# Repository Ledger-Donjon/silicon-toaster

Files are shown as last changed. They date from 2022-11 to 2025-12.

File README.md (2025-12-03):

# SiliconToaster

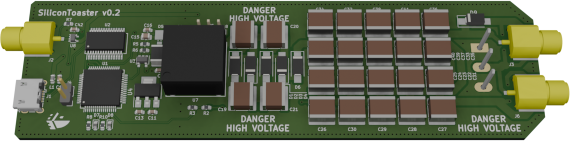
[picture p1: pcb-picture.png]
SiliconToaster


SiliconToaster is an open-source hardware electromagnetic fault injection device, designed for hardware security research. It has the following features:

- Software programmable voltage, from 0 V to 1000 V.
- Stored energy: 1 J at 1000 V.
- Capable of multiple fault injection.
- Dual socket coil mounting, for polarity selection.
- USB-only powered.

**Warning: this device is experimental and for research purpose only. High-voltage is exposed on the PCB, which can present electrical hazard. Use with caution and at your own risk. Beware that the coil body is connected to the high potential, NOT at the ground. Also, the exposed capacitor bank stores an important amount of energy.**

## Building the firmware

To build the firmware, rust shall be installed on your system (see [instructions](https://www.rust-lang.org/tools/install) for installation).

The rust toolchain for Armv6-M Thumb must be installed:

```
rustup target add thumbv6m-none-eabi
```

The firmware can then be compiled using cargo:

```
cd firmware
cargo objcopy --release --bin silicontoaster -- -O binary silicontoaster.bin
```

To flash the device, stm32flash utility is required. The MCU bootloader can be enabled by shorting the header close to the USB connector using a jumper, before connecting the PCB on USB. Then the following command will flash the MCU (replace `/dev/ttyUSB0` with the serial device in your situation):

```
stm32flash -w silicontoaster.bin -v -g 0 /dev/ttyUSB0
```

Alternatively, a makefile can run those steps:

```
cd firmware
make all
make flash
```

To enable device recognition, the FTDI USB-serial converter must be flashed using ftdi_eeprom tool. Warning: be sure no other FTDI device is connected before running this command!

```
cd ftdi
bash flash.sh
```

## Running the software

To use the device, run `python3 silicontoaster/tool.py`. This will run a graphical interface that allows setting the operating voltage and display in real-time the voltage in the capacitors bank.

When running for the first time, configure the charge pump PID settings to `Kp`, `Ki` and `Kd` to 1. Be sure to have the jumper J5 installed (position closest to the USB).

The provided calibration values should work fine by default, it is not necessary to calibrate the device by yourself unless you want more accurate measurements.

## Publication

This work was published in our [Paper](https://eprint.iacr.org/2020/1115.pdf) and presented during [Hardwear.io 2020 conference](https://hardwear.io/archives/netherlands-2020/).

## Licensing

SiliconToaster is released under GNU Lesser General Public License version 3 (LGPLv3). See LICENSE and LICENSE.LESSER for license detail.

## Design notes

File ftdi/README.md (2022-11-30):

# FTDI EEPROM programming

Disconnect all USB-to-serial devices but the SiliconToaster.

Install the package `ftdi_eeprom` and execute the `flash.sh` script as root to
program the EEPROM memory of the SiliconToaster FT232H device. This will
configure the vendor and description strings to respectively "Ledger" and
"SiliconToaster".

Configuring the EEPROM is optional, but when programmed, the software is able
to recognize automatically which serial port corresponds to the SiliconToaster.

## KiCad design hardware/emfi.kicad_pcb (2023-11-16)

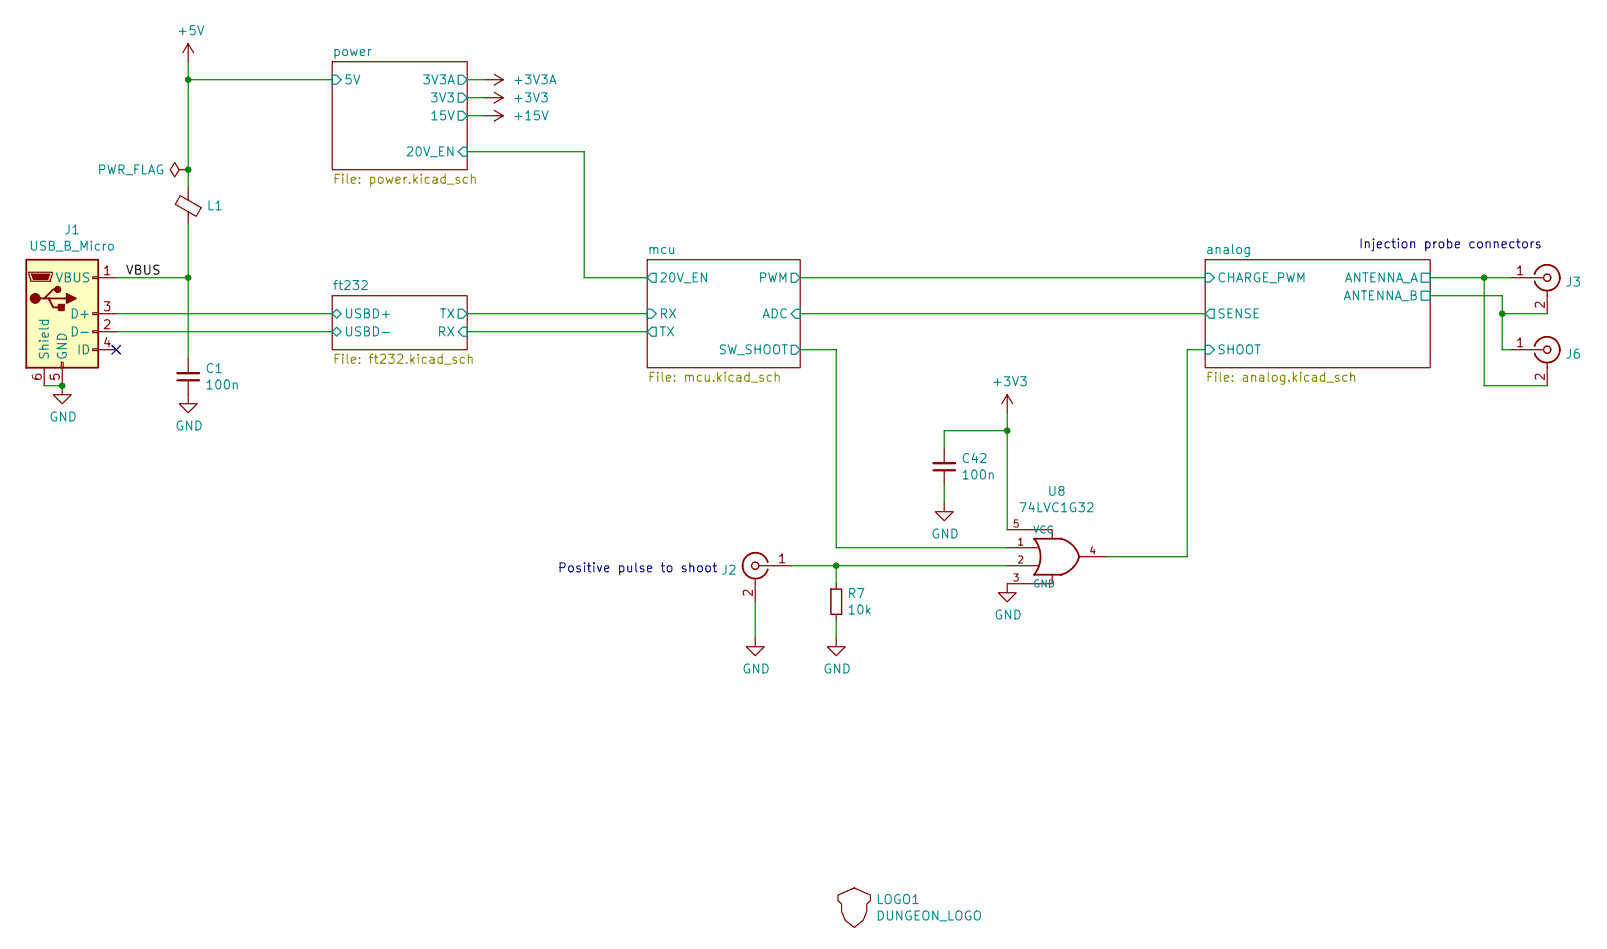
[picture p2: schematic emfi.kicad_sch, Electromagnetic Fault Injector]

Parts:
C1, C42: 100n; C_0603_1608Metric; Voltage 25
J1: USB_B_Micro; USB_Micro-B_Wuerth_629105150521
J2, J3, J6: Conn_Coaxial; SAMTEC_SMA_J_P_H_ST_EM3
L1: Ferrite_Bead_Small; L_0603_1608Metric
LOGO1: DUNGEON_LOGO; donjon-2000
R7: 10k; R_0603_1608Metric
U8: 74LVC1G32; SOT-353_SC-70-5

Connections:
+3V3: C42.2, U8.5 (VCC); also elsewhere on the board
+5V: L1.2; also elsewhere on the board
/VBUS: C1.2, J1.1 (VBUS), L1.1
/analog/ANTENNA_A: J3.1 (In), J6.2 (Ext); also elsewhere on the board
/analog/ANTENNA_B: J3.2 (Ext), J6.1 (In); also elsewhere on the board
/analog/SHOOT: U8.4; also elsewhere on the board
/ft232/USBD+: J1.3 (D+); also elsewhere on the board
/ft232/USBD-: J1.2 (D-); also elsewhere on the board
/mcu/SW_SHOOT: U8.1; also elsewhere on the board
GND: C1.1, C42.1, J1.5 (GND), J1.6 (Shield), J2.2 (Ext), R7.2, U8.3 (GND); also elsewhere on the board
unnamed: J2.1 (In), R7.1, U8.2

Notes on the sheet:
Positive pulse to shoot
Injection probe connectors

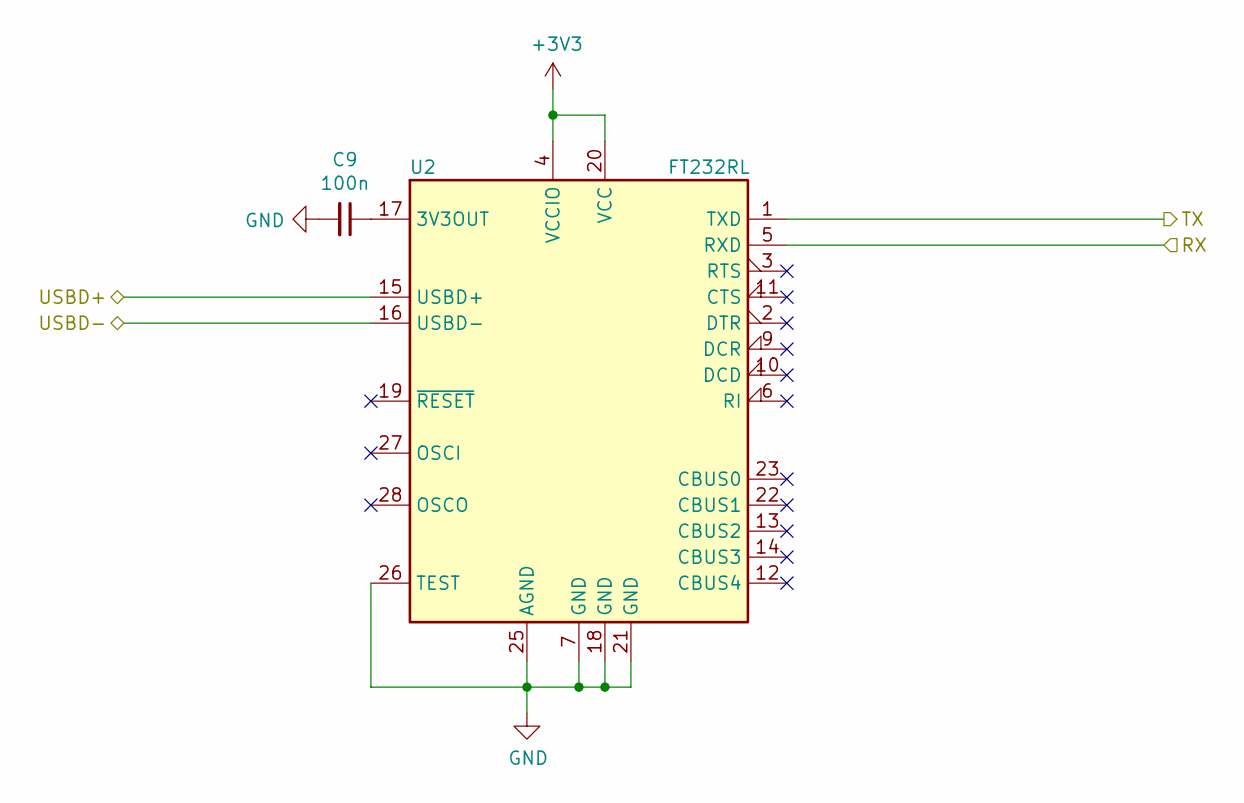
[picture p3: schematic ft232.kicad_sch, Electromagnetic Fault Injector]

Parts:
C9: 100n; C_0603_1608Metric; Voltage 25
U2: FT232RL; SSOP-28_5.3x10.2mm_P0.65mm

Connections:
+3V3: U2.4 (VCCIO), U2.20 (VCC); also elsewhere on the board
/ft232/RX: U2.5 (RXD); also elsewhere on the board
/ft232/USBD+: U2.15 (USBD+); also elsewhere on the board
/ft232/USBD-: U2.16 (USBD-); also elsewhere on the board
/mcu/RX: U2.1 (TXD); also elsewhere on the board
GND: C9.2, U2.7 (GND), U2.18 (GND), U2.21 (GND), U2.25 (AGND), U2.26 (TEST); also elsewhere on the board
unnamed: C9.1, U2.17 (3V3OUT)

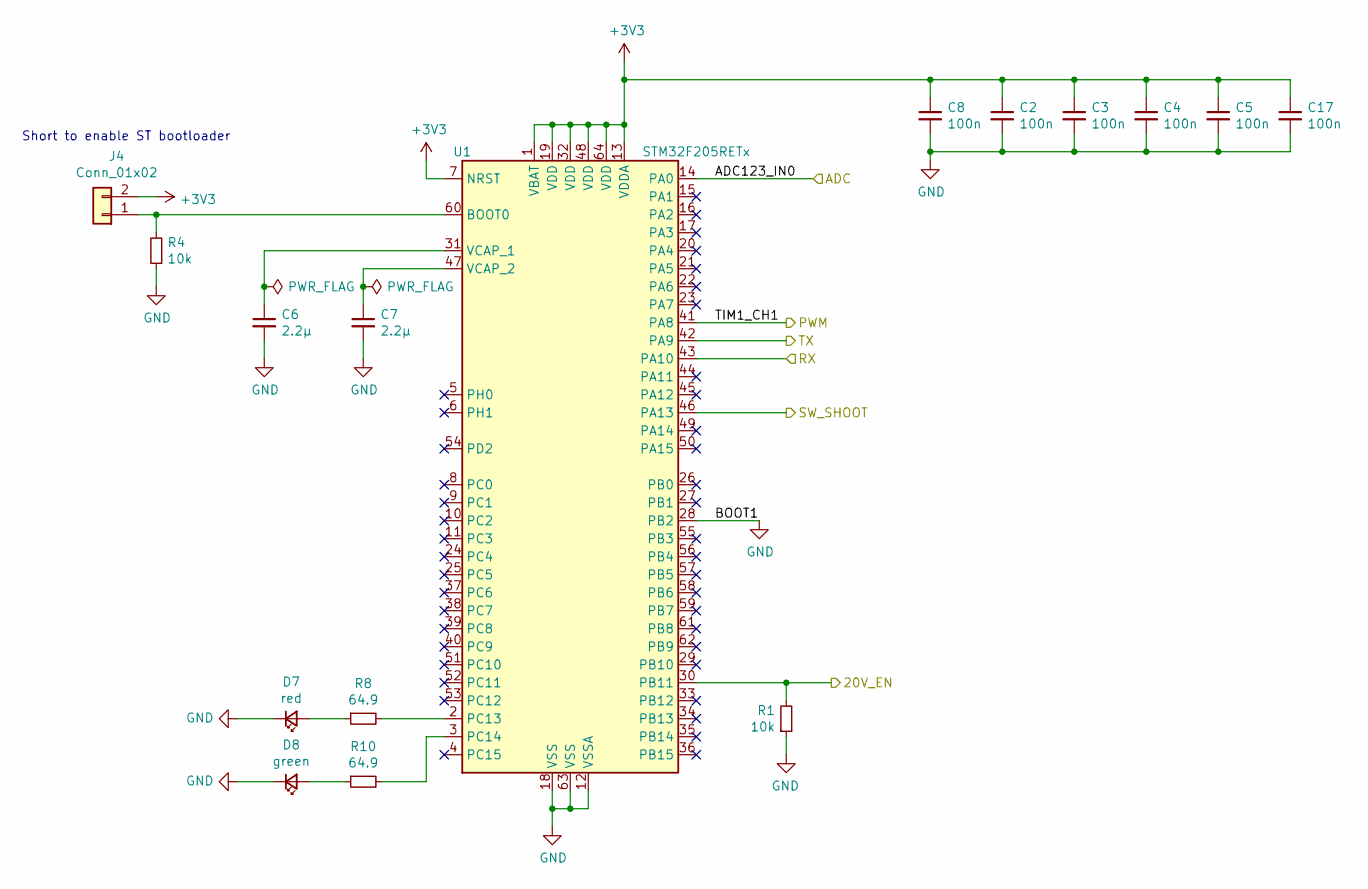
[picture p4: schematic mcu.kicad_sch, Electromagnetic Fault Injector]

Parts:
C2, C3, C4, C5, C8, C17: 100n; C_0603_1608Metric; Voltage 25
C6, C7: 2.2µ; C_0603_1608Metric; Voltage 25
D7: red; D_0603_1608Metric
D8: green; D_0603_1608Metric
J4: Conn_01x02; PinHeader_1x02_P2.54mm_Vertical
R1, R4: 10k; R_0603_1608Metric
R8, R10: 64.9; R_0603_1608Metric
U1: STM32F205RETx; LQFP-64_10x10mm_P0.5mm

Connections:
+3V3: C2.1, C3.1, C4.1, C5.1, C8.1, C17.1, J4.2, U1.1 (VBAT), U1.7 (NRST), U1.13 (VDDA), U1.19 (VDD), U1.32 (VDD), U1.48 (VDD), U1.64 (VDD); also elsewhere on the board
/analog/CHARGE_PWM: U1.41 (PA8); also elsewhere on the board
/ft232/RX: U1.42 (PA9); also elsewhere on the board
/mcu/20V_EN: R1.2, U1.30 (PB11); also elsewhere on the board
/mcu/ADC: U1.14 (PA0); also elsewhere on the board
/mcu/RX: U1.43 (PA10); also elsewhere on the board
/mcu/SW_SHOOT: U1.46 (PA13); also elsewhere on the board
GND: C2.2, C3.2, C4.2, C5.2, C6.2, C7.2, C8.2, C17.2, D7.1 (K), D8.1 (K), R1.1, R4.1, U1.12 (VSSA), U1.18 (VSS), U1.28 (PB2), U1.63 (VSS); also elsewhere on the board
unnamed: C6.1, U1.31 (VCAP_1)
unnamed: C7.1, U1.47 (VCAP_2)
unnamed: D7.2 (A), R8.1
unnamed: D8.2 (A), R10.1
unnamed: J4.1, R4.2, U1.60 (BOOT0)
unnamed: R8.2, U1.2 (PC13)
unnamed: R10.2, U1.3 (PC14)

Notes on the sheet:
Short to enable ST bootloader

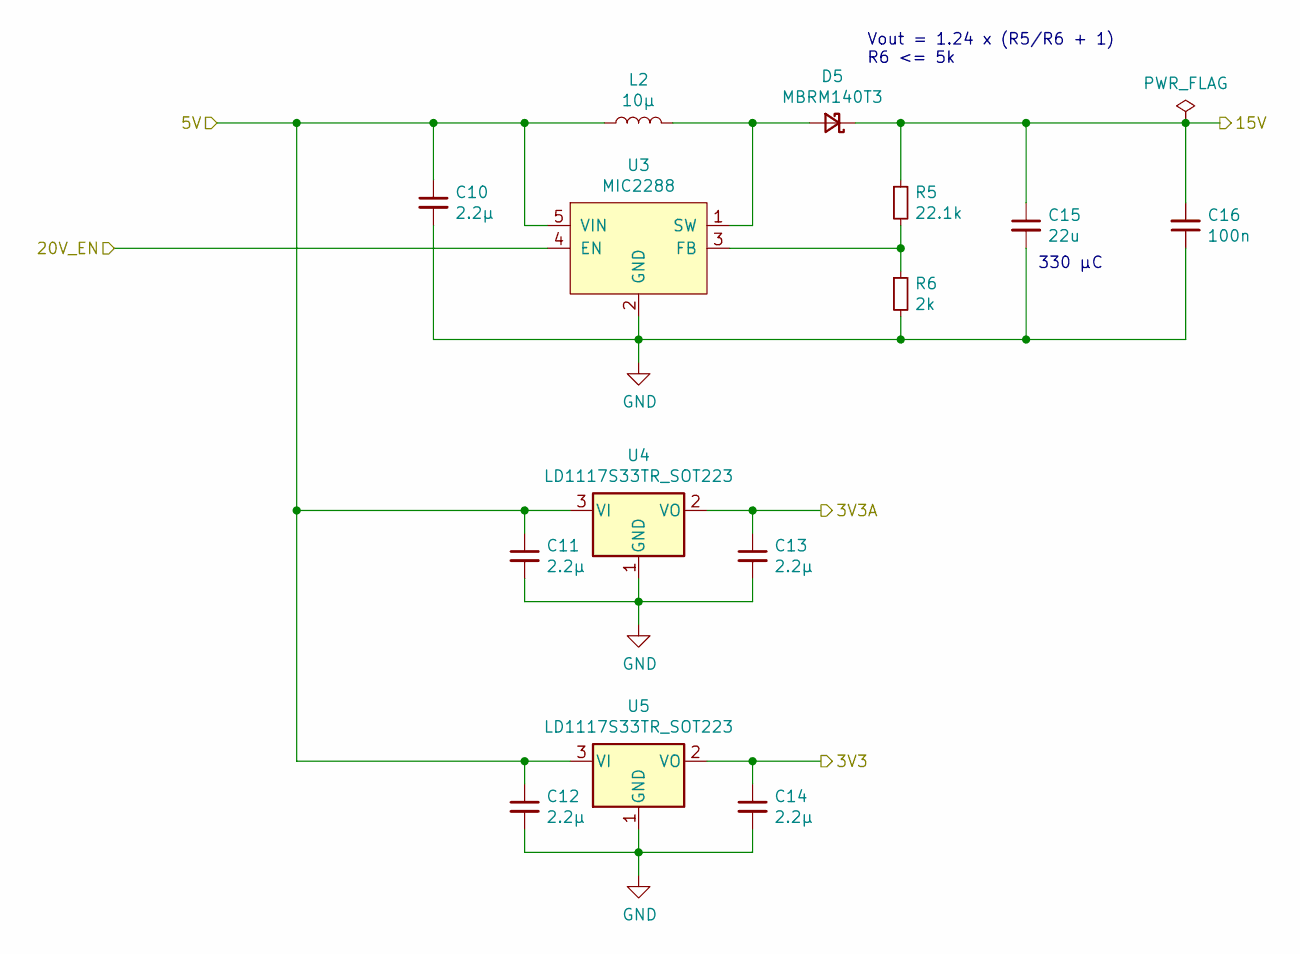
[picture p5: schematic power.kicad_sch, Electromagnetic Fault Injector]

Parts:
C10, C11, C12, C13, C14: 2.2µ; C_0603_1608Metric; Voltage 25
C15: 22u; C_0805_2012Metric; Voltage 25
C16: 100n; C_0603_1608Metric; Voltage 25
D5: MBRM140T3; D_Powermite_AK
L2: 10µ; L_1812_4532Metric
R5: 22.1k; R_0603_1608Metric
R6: 2k; R_0603_1608Metric
U3: MIC2288; SOT-23-5
U4, U5: LD1117S33TR_SOT223; SOT-223-3_TabPin2

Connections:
+3V3: C14.1, U5.2 (VO); also elsewhere on the board
+3V3A: C13.1, U4.2 (VO); also elsewhere on the board
+5V: C10.1, C11.1, C12.1, L2.1, U3.5 (VIN), U4.3 (VI), U5.3 (VI); also elsewhere on the board
+15V: C15.1, C16.2, D5.1 (K), R5.1; also elsewhere on the board
/mcu/20V_EN: U3.4 (EN); also elsewhere on the board
GND: C10.2, C11.2, C12.2, C13.2, C14.2, C15.2, C16.1, R6.2, U3.2 (GND), U4.1 (GND), U5.1 (GND); also elsewhere on the board
unnamed: D5.2 (A), L2.2, U3.1 (SW)
unnamed: R5.2, R6.1, U3.3 (FB)

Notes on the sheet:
330 µC
Vout = 1.24 x (R5/R6 + 1) R6 <= 5k

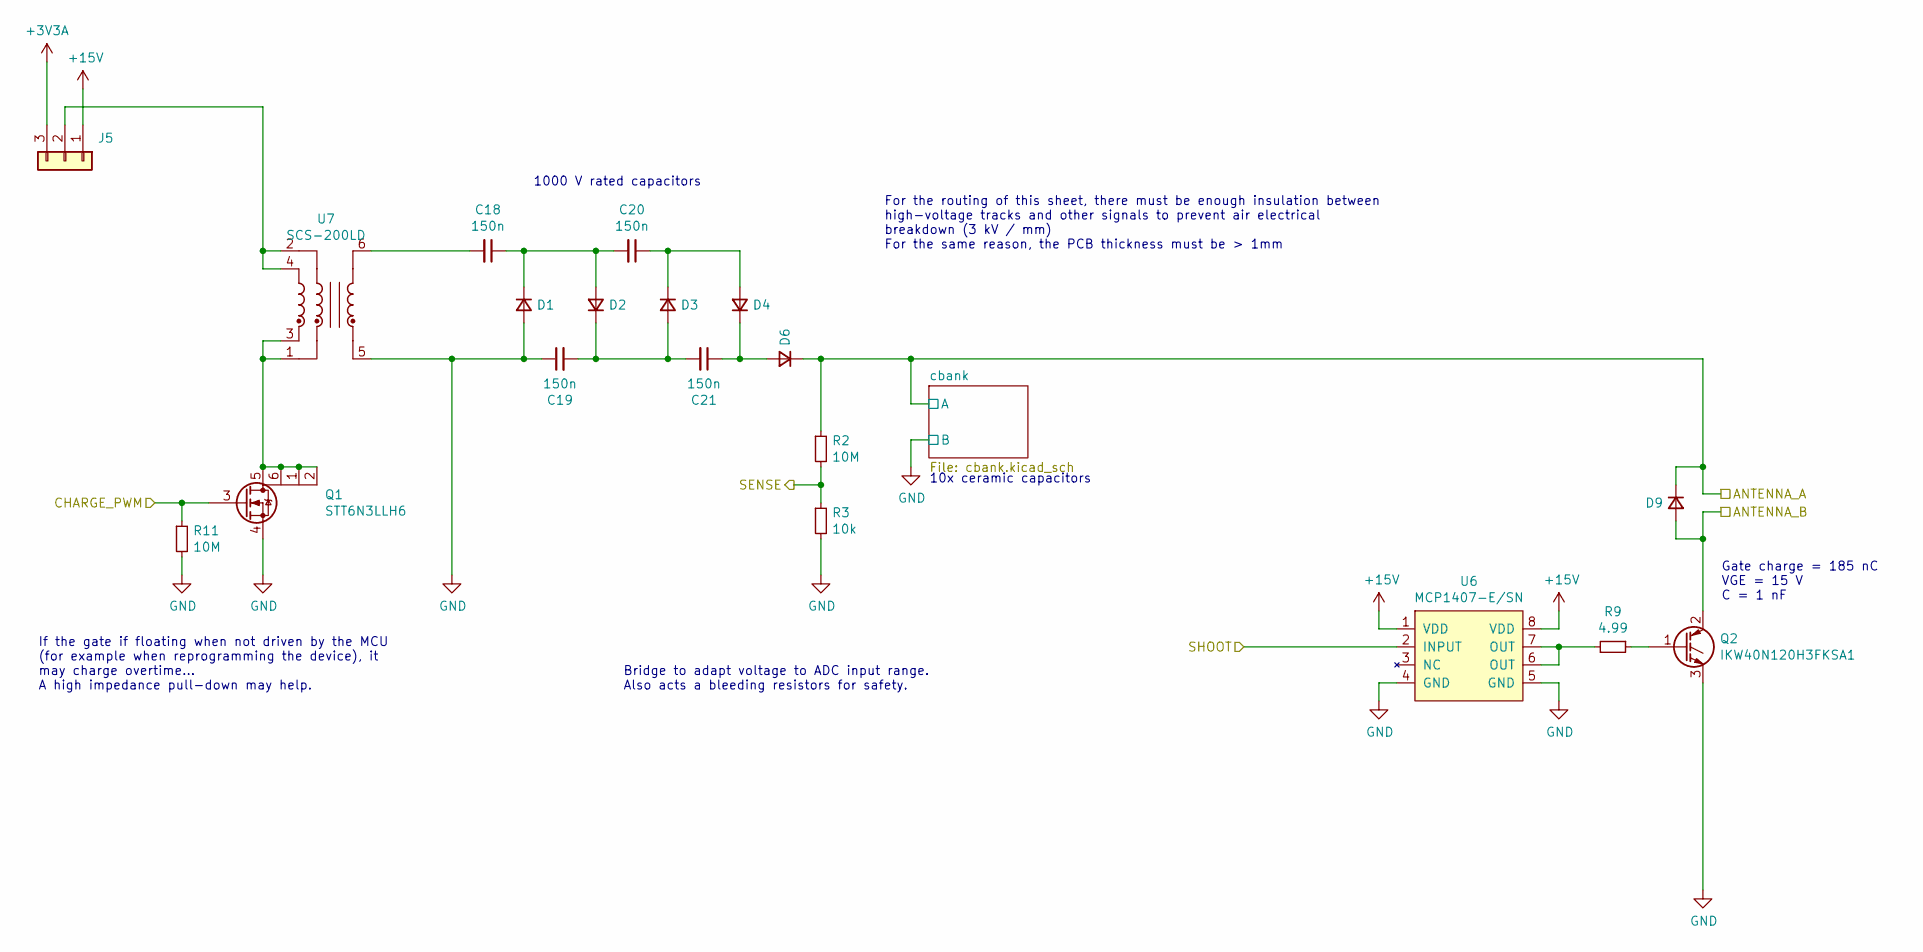
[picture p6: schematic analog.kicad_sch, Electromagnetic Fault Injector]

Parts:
C18, C19, C20, C21: 150n; C_2225_5664Metric_Pad1.80x6.60mm_HandSolder; Voltage 1000
D1, D2, D3, D4, D6, D9: US1K-E3/61T; D_SMA_Handsoldering
J5: Conn_01x03; PinHeader_1x03_P2.54mm_Vertical
Q1: STT6N3LLH6; SOT-23-6
Q2: IKW40N120H3FKSA1; TO-247-3_Horizontal_TabDown_NoTabDrill
R2, R11: 10M; R_0603_1608Metric
R3: 10k; R_0603_1608Metric
R9: 4.99; R_0603_1608Metric
U6: MCP1407-E/SN; SOIC-8_3.9x4.9mm_P1.27mm
U7: SCS-200LD; SCS-200L

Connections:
+3V3A: J5.3; also elsewhere on the board
+15V: J5.1, U6.1 (VDD), U6.8 (VDD); also elsewhere on the board
/analog/ANTENNA_A: D6.1 (K), D9.1 (K), R2.1; also elsewhere on the board
/analog/ANTENNA_B: D9.2 (A), Q2.2 (C); also elsewhere on the board
/analog/CHARGE_PWM: Q1.3, R11.1; also elsewhere on the board
/analog/SHOOT: U6.2 (INPUT); also elsewhere on the board
/mcu/ADC: R2.2, R3.1; also elsewhere on the board
GND: C19.1, D1.2 (A), Q1.4, Q2.3 (E), R3.2, R11.2, U6.4 (GND), U6.5 (GND), U7.5; also elsewhere on the board
unnamed: C18.1, C20.2, D1.1 (K), D2.2 (A)
unnamed: C18.2, U7.6
unnamed: C19.2, C21.2, D2.1 (K), D3.2 (A)
unnamed: C20.1, D3.1 (K), D4.2 (A)
unnamed: C21.1, D4.1 (K), D6.2 (A)
unnamed: J5.2, U7.2, U7.4
unnamed: Q1.1, Q1.2, Q1.5, Q1.6, U7.1, U7.3
unnamed: Q2.1 (G), R9.1
unnamed: R9.2, U6.6 (OUT), U6.7 (OUT)

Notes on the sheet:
10x ceramic capacitors
Gate charge = 185 nC VGE = 15 V C = 1 nF
If the gate if floating when not driven by the MCU (for example when reprogramming the device), it may charge overtime... A high impedance pull-down may help.
For the routing of this sheet, there must be enough insulation between high-voltage tracks and other signals to prevent air electrical breakdown (3 kV / mm) For the same reason, the PCB thickness must be > 1mm
1000 V rated capacitors
Bridge to adapt voltage to ADC input range. Also acts a bleeding resistors for safety.

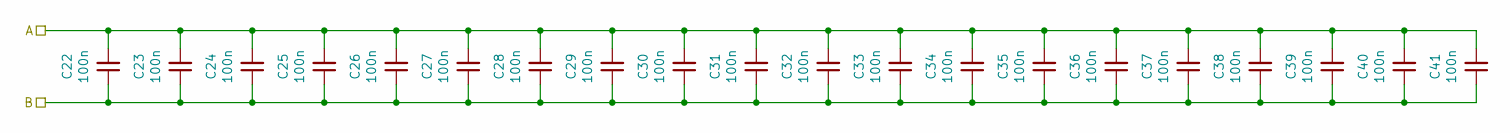
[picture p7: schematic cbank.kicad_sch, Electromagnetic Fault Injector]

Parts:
C22, C23, C24, C25, C26, C27, C28, C29, C30, C31, C32, C33, C34, C35, C36, C37, C38, C39, C40, C41: 100n; C_2225_5664Metric_Pad1.80x6.60mm_HandSolder; Voltage 1500

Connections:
/analog/ANTENNA_A: C22.2, C23.2, C24.2, C25.2, C26.2, C27.2, C28.2, C29.2, C30.2, C31.2, C32.2, C33.2, C34.2, C35.2, C36.2, C37.2, C38.2, C39.2, C40.2, C41.2; also elsewhere on the board
GND: C22.1, C23.1, C24.1, C25.1, C26.1, C27.1, C28.1, C29.1, C30.1, C31.1, C32.1, C33.1, C34.1, C35.1, C36.1, C37.1, C38.1, C39.1, C40.1, C41.1; also elsewhere on the board

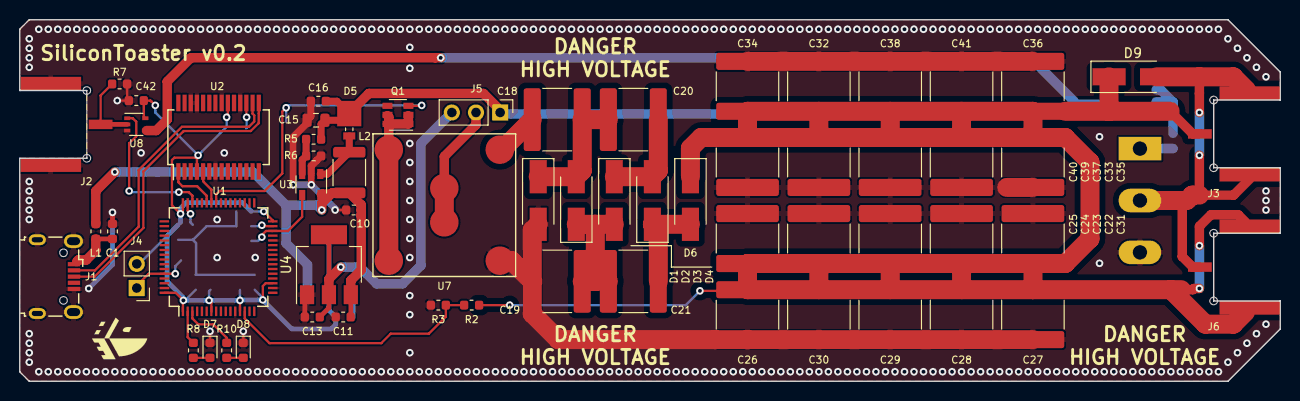
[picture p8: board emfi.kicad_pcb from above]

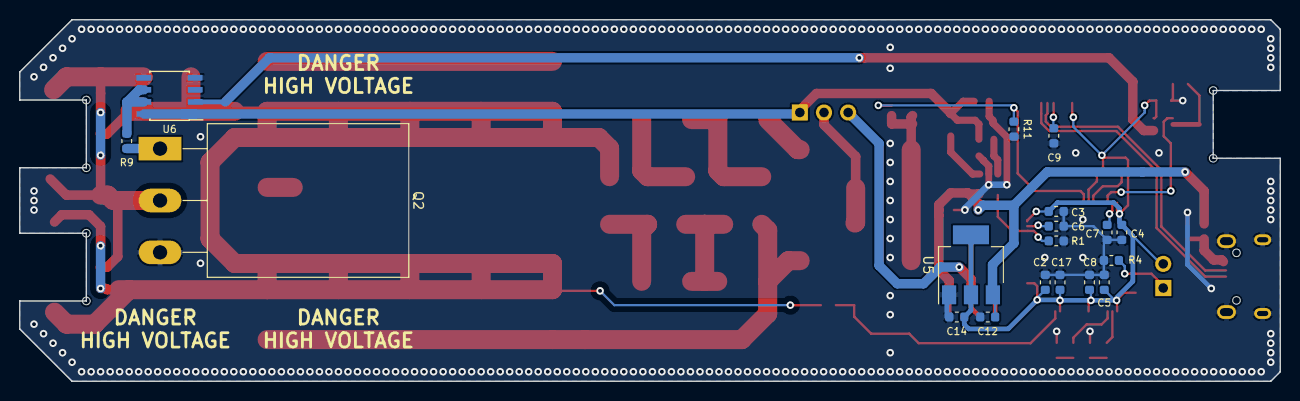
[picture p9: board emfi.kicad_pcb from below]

Board: 2 copper layers, 132.5 x 38.0 mm, 81 parts (18 on the bottom side), 37 nets.

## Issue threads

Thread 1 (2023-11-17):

Center pin on J5 supposed to be connected to 3.3V? MCU

jhutchinfosec, 2023-11-17:
I'm assuming center pin on J5 is supposed to be connected to the 3.3v pin right next to it to complete the circuit for PWM signal on the transformer, correct? Otherwise, where will the current flow to once it exits the primary to J5? When I do this though, the MCU stops responding, but when I attach to an external power supply it works well (well up to ~1050-1070v, I'm not getting 1200 but still pretty good). Am I thinking about this wrong?

Is it meant to be using a USB hub with mains power adapter or just connecting directly to collection device?

jhutchinfosec, 2023-11-17:
was able to get it working under its own power up to about 880v by inserting a 2ohm current limiting resistor between primary coil and Vcc (3.3v). Couldn't lower the value to draw off more current for 1000v without reseting the mcu, might try messing with the PWM timing to see if that might help.

jhutchinfosec, 2023-11-17:
Tried, mmo_debug_pid branch, issue seems to be fixed in this branch, able to charge to ~1100v from the onboard power supply without needing to add current limiting resistor.

Closed 2023-11-17.

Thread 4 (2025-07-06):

requirements

NEO999000, 2025-07-06:
Good day. I assembled a toaster and it is not difficult to flash. But the scripts do not work. Tell me what system you are running and what requirements you have installed, namely Versions. PyQt5 simply does not work and quicklog is completely empty on Windows 10. It only works with quicklogs and then calibration scripts. Will there be normal instructions on assembling and configuring the equipment? It's a pity I have already assembled it and it all rests on the software.

sirhcel, 2025-09-24:
I did some spring cleaning for my bring-up of the device with #3. This covers at least the issue with quicklogs you mentioned here @NEO999000.

Closed 2025-10-03.

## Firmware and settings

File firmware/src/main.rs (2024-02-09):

#![no_std]
#![no_main]

mod adc_control;
mod flash;
mod system_timer;
mod txrx_utils;
use adc_control::ADCControl;
use core::panic::PanicInfo;
use flash::Flash;
use stm32f2::stm32f215;
use system_timer::SystemTimer;
use txrx_utils::{handler_usart1, usart1_has_data, TxRx};

#[panic_handler]
/// Panic handler: turns the high voltage off and make the red led blinking
fn panic(_: &PanicInfo) -> ! {
    unsafe {
        // In case of panic, the peripherals may have already been taken, and we
        // cannot take it again... But this is panic, we can do dirty things and
        // call steal to use peripherals anyway!
        // Here we just blink the red LED forever to indicate there is a
        // problem.
        let peripherals = stm32f215::Peripherals::steal();
        let mut sys_timer = SystemTimer::new(&peripherals.STK);
        set_high_voltage_generator(&peripherals, false);
        set_led_green(&peripherals.GPIOC, false);
        loop {
            set_led_red(&peripherals.GPIOC, true);
            delay_ms(&mut sys_timer, 250);
            set_led_red(&peripherals.GPIOC, false);
            delay_ms(&mut sys_timer, 250);
        }
    }
}

pub extern "C" fn handler_default() {
    loop {}
}

#[link_section = ".isr_vectors.reset"]
#[no_mangle]
pub static RESET_VECTOR: unsafe extern "C" fn() -> ! = _start;

#[link_section = ".isr_vectors"]
#[no_mangle]
pub static INTERRUPT_VECTORS: [unsafe extern "C" fn(); 95] = {
    let mut v: [unsafe extern "C" fn(); 95] = [handler_default; 95];
    v[51] = handler_usart1;
    v
};

/// Toggle the red LED on or off.
/// # Arguments
/// * `gpio` - This method needs to borrow the GPIO-C.
/// * `state` - true to turn on the LED, false to turn off.
fn set_led_red(gpio: &stm32f215::GPIOC, state: bool) {
    gpio.odr.modify(|_, w| w.odr13().bit(state));
}

/// Toggle the green LED on or off.
/// # Arguments
/// * `gpio` - This method needs to borrow the GPIO-C.
/// * `state` - true to turn on the LED, false to turn off.
fn set_led_green(gpio: &stm32f215::GPIOC, state: bool) {
    gpio.odr.modify(|_, w| w.odr14().bit(state));
}

/// Enable or disable on-board 15 V regulator.
/// # Arguments
/// * `gpio` - This method needs to borrow the GPIO-B.
/// * `state` - true to turn on the regulator, false to turn off.
fn set_15v_regulator(gpio: &stm32f215::GPIOB, state: bool) {
    gpio.odr.modify(|_, w| w.odr11().bit(state));
}

/// Approximated delay function. Precise enough for what we need to do...
/// # Arguments
/// * `duration` - The time in ms we want to wait
#[inline(never)]
fn delay_ms(sys_timer: &mut SystemTimer, duration: u32) {
    let duration_in_ticks = (duration as u64) * SystemTimer::FREQ / 1000;
    let start = sys_timer.get_ticks();
    let mut now = start;
    while (now - start) < duration_in_ticks {
        now = sys_timer.get_ticks();
    }
}

/// Enable or disable very-high voltage generation by enabling or disabling the
/// PWM output and the on-board 15 V generator.
/// # Arguments
/// * `peripherals` - This method needs to borrow the peripherals.
/// * `state` - true to enable, false to disable.
fn set_high_voltage_generator(peripherals: &stm32f215::Peripherals, state: bool) {
    // When PWM if off, it seems the output pin is left floating. This is not
    // good because charges will accumulate on the gate of the charge pump
    // transistor, making it always conductive after a while and creating a
    // permanent shortcut. To solve this issue, we force output to zero when
    // high voltage generation if off.
    if state {
        peripherals.TIM1.bdtr.write(|w| w.moe().set_bit());
        peripherals
            .GPIOA
            .moder
            .modify(|_, w| w.moder8().alternate());
    } else {
        peripherals.GPIOA.odr.modify(|_, w| w.odr8().clear_bit());
        peripherals.GPIOA.moder.modify(|_, w| w.moder8().output());
        peripherals.TIM1.bdtr.write(|w| w.moe().clear_bit());
    }
}

/// Configure PWM parameters for high voltage generation. If the parameters are
/// invalid, this method may panic.
/// # Arguments
/// * `tim1` - This method needs to borrow the timer.
/// * `period` - Maximum counter value to the timer. Defines the period of the
///     PWM.
/// * `width` - Comparator value for the counter. Defines the PWM positive pulse
///     width.
fn set_pwm_parameters(tim1: &stm32f215::TIM1, period: u16, width: u16) -> Result<(), ()> {
    if width > period {
        return Err(());
    }
    if period == 0 {
        return Err(());
    }
    tim1.arr.write(|w| w.arr().bits(period - 1));
    tim1.ccr1().write(|w| w.ccr().bits(width));
    Ok(())
}

/// Perform software shoot.
/// # Arguments
/// * `gpio` - This method needs to borrow the GPIO-A.
/// * `duration` - Pulse duration, in number of program loop.
fn software_shoot(gpio: &stm32f215::GPIOA, duration: u16) {
    gpio.odr.modify(|_, w| w.odr13().set_bit());
    for _ in 0..duration {
        cortex_m::asm::nop();
    }
    gpio.odr.modify(|_, w| w.odr13().clear_bit());
}

/// Configure internal Flash memory interface.
/// This changes the Flash latency to be compatible with PLL settings.
/// # Arguments
/// * `flash` - This method needs to borrow the flash register
fn setup_flash(flash: &stm32f215::FLASH) {
    unsafe {
        flash.acr.modify(|_, w| w.latency().bits(2));
    }
}

/// Configure PLL
/// # Arguments
/// * `rcc` - This method needs to borrow the Reset and clock control register
fn setup_pll(rcc: &stm32f215::RCC) {
    // Disable PLL
    rcc.cr.modify(|_, w| w.pllon().clear_bit());
    // HSI = 16 MHz
    // F = ((HSI (N / M) / P
    // Constraints to be respected:
    // 50 <= N <= 432
    // 2 <= M <= 63
    // Here the target frequency is 64 MHz
    unsafe {
        rcc.pllcfgr
            .modify(|_, w| w.plln().bits(64).pllm().bits(8).pllp().div2());
    }
    // Enable PLL and wait it to be locked.
    rcc.cr.modify(|_, w| w.pllon().set_bit());
    while !rcc.cr.read().pllrdy().bit() {}
    // Switch to PLL clock
    rcc.cfgr.modify(|_, w| w.sw().pll());
}

#[no_mangle]
pub extern "C" fn _start() -> ! {
    // Get .bss segment position for .bss initialization performed in _start.
    extern "C" {
        static _bss: u32;
        static _ebss: u32;
    }
    // Clear RAM of .bss section before doing anything!
    unsafe {
        for i in ((&_bss as *const u32) as u32..(&_ebss as *const u32) as u32).step_by(4) {
            core::ptr::write_volatile(i as *mut u32, 0u32);
        }
    }

    let peripherals = stm32f215::Peripherals::take().unwrap();
    setup_flash(&peripherals.FLASH);
    let rcc = &peripherals.RCC;
    setup_pll(rcc);

    rcc.apb2enr.write(|w| w.usart1en().set_bit());
    // USART1 uses PA9 for TX and PA10 for RX.
    // LEDs are connected to PC13 and PC14.
    // Enable clock for PORT A, PORT B and PORT C peripherals.
    rcc.ahb1enr.write(|w| {
        w.gpioaen()
            .set_bit()
            .gpioben()
            .set_bit()
            .gpiocen()
            .set_bit()
    });
    peripherals
        .GPIOC
        .moder
        .modify(|_, w| w.moder13().output().moder14().output());
    set_15v_regulator(&peripherals.GPIOB, true);
    peripherals.GPIOB.moder.write(|w| w.moder11().output());

    // Configure UART1
    // UART Enable, Transmitter Enable, Receiver Enable
    let usart1 = &peripherals.USART1;
    usart1
        .cr1
        .write(|w| w.ue().set_bit().te().set_bit().re().set_bit());
    usart1.cr2.write(|w| w.stop().bits(2));
    // Baudrate is Fck/(8*(2-OVER8)*DIV)
    // Fck = 64 MHz
    // OVER8 = 0
    // DIV = BRR / 16
    // Here we set 9600 bps
    let brr_value = 6666;
    usart1.brr.write(|w| {
        w.div_mantissa()
            .bits(brr_value >> 4)
            .div_fraction()
            .bits((brr_value & 0x0f) as u8)
    });
    // Select Alternate Function 7 (USART1) for PA9 and PA10.
    let gpioa = &peripherals.GPIOA;
    gpioa.afrh.write(|w| w.afrh10().af7().afrh9().af7());
    gpioa
        .moder
        .write(|w| w.moder10().alternate().moder9().alternate());
    // Configure PA9 and PA10 GPIOs in high frequency
    gpioa
        .ospeedr
        .write(|w| w.ospeedr10().very_high_speed().ospeedr9().very_high_speed());
    // Enable interrupt for USART1
    usart1.cr1.modify(|_, w| w.rxneie().set_bit());
    unsafe {
        cortex_m::peripheral::NVIC::unmask(stm32f215::Interrupt::USART1);
    }

    // Configure SW_SHOOT signal on pin PA13.
    gpioa.ospeedr.modify(|_, w| w.ospeedr13().very_high_speed());
    gpioa.moder.modify(|_, w| w.moder13().output());

    // System timer to track time between two controls.
    let mut sys_timer = SystemTimer::new(&peripherals.STK);

    // Give some time for the FT232 to boot-up.
    set_led_green(&peripherals.GPIOC, true);
    set_led_red(&peripherals.GPIOC, true);
    delay_ms(&mut sys_timer, 500);

    // Variable to track last applied PWM parameters.
    let mut current_period: u16 = 800;
    let mut current_width: u16 = 5;

    // Object to perform flash operations.
    let flash = Flash {
        flash: &peripherals.FLASH,
    };

    // ADC's output Control, containing a PID.
    // The constructor reads the value from flash if it exists, otherwise
    // get generic values.
    let mut adc_ctrl = ADCControl::new();

    // Configure PWM using TIM1.
    // PWM output on PA8. Alternate Function 1.
    peripherals.RCC.apb2enr.modify(|_, w| w.tim1en().set_bit());
    let tim1 = &peripherals.TIM1;
    tim1.cr1.write(|w| w.cen().set_bit());
    set_pwm_parameters(tim1, current_period, current_width).unwrap();
    tim1.ccmr1_output().write(|w| w.oc1m().pwm_mode1());
    tim1.ccer.write(|w| w.cc1e().set_bit());
    gpioa.ospeedr.modify(|_, w| w.ospeedr8().very_high_speed());
    gpioa.afrh.modify(|_, w| w.afrh8().af1());
    gpioa.moder.modify(|_, w| w.moder8().alternate());

    // Configure ADC.
    // Input is PA0.
    peripherals.RCC.apb2enr.modify(|_, w| w.adc1en().set_bit());
    gpioa.moder.modify(|_, w| w.moder0().analog());
    let adc1 = &peripherals.ADC1;
    adc1.cr2.write(|w| w.cont().set_bit().adon().set_bit());
    adc1.cr2.modify(|_, w| w.swstart().set_bit()); // Start the conversion
    adc1.smpr2.write(|w| w.smp0().bits(7));

    let mut high_voltage_enabled = false;
    set_high_voltage_generator(&peripherals, high_voltage_enabled);

    let mut error = 0u16;
    loop {
        // ADC Control. Get current value and timestamp.
        let adc_result: u16 = adc1.dr.read().data().bits();
        let now = sys_timer.get_ticks();

        if adc_ctrl.needs_control(now) {
            current_width = adc_ctrl.next_control_output(adc_result, now) as u16;
            if current_width > current_period {
                current_width = current_period;
            }
            match set_pwm_parameters(tim1, current_period, current_width) {
                Ok(_) => (),
                Err(_) => error += 1,
            };
        }

        if usart1_has_data() {
            let command_byte: u8 = usart1.rx();
            match command_byte {
                0x01 => {
                    // Command to activate/deactivate the voltage generator.
                    let value: u8 = usart1.rx();
                    assert!(value <= 1);
                    high_voltage_enabled = value != 0;
                    set_high_voltage_generator(&peripherals, high_voltage_enabled);
                    usart1.tx(command_byte);
                }
                0x02 => {
                    // Command to get the raw value obtained by the ADC.
                    usart1.tx(command_byte);
                    usart1.tx(adc_result);
                }
                0x03 => {
                    // Command to set the values of PWM (period and width).
                    current_period = usart1.rx();
                    current_width = usart1.rx();
                    usart1.tx(
                        match set_pwm_parameters(tim1, current_period, current_width) {
                            Ok(_) => command_byte,
                            Err(_) => !command_byte,
                        },
                    );
                }
                0x04 => {
                    // Command to perform a software shoot.
                    let duration: u16 = usart1.rx();
                    software_shoot(&peripherals.GPIOA, duration);
                    usart1.tx(command_byte);
                }
                0x05 => {
                    // Command to get the current time from SystemTimer.
                    usart1.tx(command_byte);
                    usart1.tx(sys_timer.get_ticks());
                }
                0x06 => {
                    // Command to get the ADC Control set point.
                    usart1.tx(command_byte);
                    usart1.tx(adc_ctrl.setpoint());
                }
                0x07 => {
                    // Command to set the ADC Control set point
                    // Force to use 800 as PWM period.
                    current_period = 800;
                    adc_ctrl.set_setpoint(usart1.rx());
                    usart1.tx(command_byte);
                }
                0x08 => {
                    // Command to get the values of PWM (period and width).
                    usart1.tx(command_byte);
                    usart1.tx(current_period);
                    usart1.tx(current_width);
                }
                0x0A => {
                    // Command to retrieve the values of the
                    // Kp, Ki, Kd coefficients of the ADC Control
                    // Optionally restore those values from Flash.
                    let read_from_flash: bool = usart1.rx();
                    if read_from_flash {
                        adc_ctrl.read_from_flash();
                    }
                    usart1.tx(command_byte);
                    usart1.tx(adc_ctrl.pid.kp);
                    usart1.tx(adc_ctrl.pid.ki);
                    usart1.tx(adc_ctrl.pid.kd);
                    usart1.tx(adc_ctrl.control_ticks);
                }
                0x0B => {
                    // Command to set the values of the
                    // Kp, Ki, Kd coefficients of the ADC Control
                    // Optionally store those values in Flash.
                    let store_in_flash: bool = usart1.rx();
                    adc_ctrl.pid.kp = usart1.rx();
                    adc_ctrl.pid.ki = usart1.rx();
                    adc_ctrl.pid.kd = usart1.rx();
                    adc_ctrl.control_ticks = usart1.rx();
                    if store_in_flash {
                        adc_ctrl.store_in_flash(&flash);
                    }
                    usart1.tx(command_byte);
                }
                0x0C => {
                    // Command to set more values of the configuration of the ADC Control
                    adc_ctrl.pid.p_limit = usart1.rx();
                    adc_ctrl.pid.i_limit = usart1.rx();
                    adc_ctrl.pid.d_limit = usart1.rx();
                    adc_ctrl.pid.output_limit = usart1.rx();
                    usart1.tx(command_byte);
                }
                0x0D => {
                    // Command to retrieve more values of the configuration of the ADC Control
                    usart1.tx(command_byte);
                    usart1.tx(adc_ctrl.pid.p_limit);
                    usart1.tx(adc_ctrl.pid.i_limit);
                    usart1.tx(adc_ctrl.pid.d_limit);
                    usart1.tx(adc_ctrl.pid.output_limit);
                    usart1.tx(adc_ctrl.pid.setpoint);
                    usart1.tx(adc_ctrl.last_control);
                }
                0xAA => {
                    // Command to activate/deactivate the ADC Control.
                    let value: u8 = usart1.rx();
                    adc_ctrl.enabled = value == 1;
                    usart1.tx(command_byte);
                }
                0xAB => {
                    // Command to get the activation status of the ADC Control.
                    usart1.tx(command_byte);
                    usart1.tx(adc_ctrl.enabled);
                }
                0xEE => {
                    // Acknowledge errors.
                    usart1.tx(command_byte);
                    usart1.tx(error);
                    error = 0;
                }
                _ => {
                    // Unknown command. Panic!
                    usart1.tx(command_byte);
                    panic!();
                }
            }
        }
        let danger = (adc_result >= 67) || high_voltage_enabled;
        let has_error = error != 0;
        set_led_red(&peripherals.GPIOC, danger || has_error);
        set_led_green(&peripherals.GPIOC, !danger || has_error);
    }
}

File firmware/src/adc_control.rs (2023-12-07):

//! ADC control structure to manage the targeted value of the ADC, using the system timer, and
//! a Pid.

use crate::Flash;
use crate::SystemTimer;
use pid::Pid;

pub struct ADCControl {
    pub enabled: bool,
    // Time interval between two controls (in ticks: 1 second corresponds to 8047640 ticks).
    pub control_ticks: u64,
    pub last_control: u64,
    pub pid: Pid<f32>,
}

impl ADCControl {
    pub fn new() -> ADCControl {
        // Create a PID with limits at 150, which is the highest value permitted by the PWM
        let mut adc = ADCControl {
            enabled: false,
            control_ticks: SystemTimer::FREQ / 1000, // ~1milliseconds
            last_control: 0,
            pid: Pid::new(0.0, 150.0)
        };
        adc.pid.p_limit = 150.0;
        adc.pid.i_limit = 150.0;
        adc.pid.d_limit = 150.0;
        adc.read_from_flash();
        adc
    }

    pub fn next_control_output(&mut self, adc_result: u16, ticks: u64) -> f32 {
        // Updates the last control time and requests for next control value from PID
        self.last_control = ticks;
        // The PID object should give a value between -output_limit and output_limit
        // This seems to be broken. Sometimes the value gets out of output_limit bounds.
        self.pid.next_control_output(adc_result as f32)
        .output.clamp(-self.pid.output_limit, self.pid.output_limit)
    }

    pub fn needs_control(&self, ticks: u64) -> bool {
        // The control must be enabled and
        // the last control has been executed long time enough
        self.enabled && (ticks.abs_diff(self.last_control) > self.control_ticks)
    }

    // Getter for setpoint for the Controller.
    pub fn setpoint(&self) -> u16 {
        self.pid.setpoint as u16
    }

    // Setter for setpoint for the Controller.
    pub fn set_setpoint(&mut self, setpoint: u16) {
        self.pid.setpoint = setpoint as f32;
        self.pid.reset_integral_term();
    }

    // Magic value in flash to indicate that it contains data.
    const IS_SET: u32 = 0x444E4A4E;
    // The sector where the data will be serialized.
    const FLASH_SECTOR: u8 = 3;

    pub fn read_from_flash(&mut self) {
        let address: *const u32 = Flash::base_address_for_sector(Self::FLASH_SECTOR);
        unsafe {
            if address.read() != Self::IS_SET {
                // The memory does not contain the expected data.
                return;
            }
            self.pid.kp = f32::from_bits(address.offset(1).read());
            self.pid.ki = f32::from_bits(address.offset(2).read());
            self.pid.kd = f32::from_bits(address.offset(3).read());
            let h = address.offset(4).read() as u64;
            let l = address.offset(5).read() as u64;
            self.control_ticks = (h << 32) + l;
        }
    }

    pub fn store_in_flash(&self, flash: &Flash) {
        flash.flash_erase_sector(Self::FLASH_SECTOR);
        let base: *mut u32 = Flash::base_address_for_sector(Self::FLASH_SECTOR);
        let values = [
            Self::IS_SET, // Marker to indicate that flash contains data.
            self.pid.kp.to_bits(),
            self.pid.ki.to_bits(),
            self.pid.kd.to_bits(),
            (self.control_ticks >> 32) as u32,
            (self.control_ticks & 0xffffffff) as u32,
        ];
        flash.flash_program(base, values.as_ptr(), values.len() as isize);
    }
}

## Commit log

2019-10-29 First hardware version.
    [analog.sch, cbank.sch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]
2019-11-12 Enable PWM output on PA8.
2019-11-12 Bug fix in UART byte transmission.
    [main.rs]
2019-11-14 Enabled PLL to run at 64 MHz.
    This allows finer PWM parameters tuning.
2019-11-14 Hardware fix.
    Added pull-down resistor on PWM output of the MCU so the charge pump
    gate does not get charged when the PWM pin is floating.
    [analog.sch, emfi.kicad_pcb]
2019-11-15 Fixed IGBT footprint.
    [analog.sch, emfi.kicad_pcb]
2019-11-19 Software improvements.
    Added precise calibration to read the voltage for the current toaster.
    Now turning off the toaster when closing the tool.
2019-12-16 Improved firmware.
    Always enabling 15 V regulator to prevent USB crashes.
    Red and green LEDs state depending on ADC readout voltage for more
    safety: green is lit when the voltage on the capacitors is < 50 V and
    the charge pump is disabled.
    [main.rs]
2019-12-17 tty device from program arguments
2022-02-28 Upgraded files for KiCad 6
    [analog.kicad_sch, analog.sch, cbank.kicad_sch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]
2022-02-28 Fixed 3D models in KiCad PCB
    [emfi.kicad_pcb]
2022-09-15 Add a software limit, if exists, at each voltage reading, turns the silicon toaster off if it exceeds the limit
2022-09-15 Script to measure the resulting voltage for a given width/period PWM settings
2022-09-22 Implementation of ADCControlParams to handle Control of ADC
2022-09-22 Keep track of PWM period/width and add command to retrieve them
2022-09-22 Instanciate a SystemTimer, add a command to get current timestamp
2022-09-22 Integrate the ADC Control in the main loop.
2022-09-22 Add interpolation from calibration log.
2022-09-26 Usage of stm32f215::STK for accessing to the Systick register
2022-09-28 panic function: make it blink, and power off high voltage.
2022-09-29 ADC control
2022-09-29 Default PWM period changed to 800
2022-09-29 Get current SystemTimer's tick and time
2022-09-29 Command to get and set PID's coefs + the number of ticks between each PID feeding. Optionally stores those parameters in NVM Flash
2022-09-29 Add calibration values to reverse the conversion from Volts to RAW values of ADC
    [silicontoaster.py]
2022-09-29 Update calibration script to also compute the Volt->RAW polynom
2022-09-29 ADC Control commands
2022-10-17 Suspect next_control_output to be buggy: check the limit actually.
    [adc_control.rs]
2022-10-17 Update tool to show the voltage destination
2022-10-17 Remove calibration voltage
2022-10-17 Update calibration scripts
2022-11-30 Added board auto detection
2023-05-17 Update heapless and pid crates
2023-05-17 Disable PID by default
2023-05-17 Use system timer to compute the delay
2023-05-17 In case of setting values, return the command byte to confirm execution
2023-05-17 Add control in tool to permit the change of PWM values
2023-05-17 ADC Control enabling commands
2023-05-17 [UI] ADC Control enabling commands
2023-05-17 Record 1024 rotating values of PID inputs, and get a function to retrieve them
2023-05-17 Shortcuts to activate/deactivate timer
    [tool.py]
2023-05-19 Initialize the PID with 150 as outputs limits
2023-05-19 Remove debug feature: record of ADC output
2023-05-19 Change the next_control_output return value to give directly the PID output. Also ensure that the output limit is applied.
2023-05-19 Connect the button after being modified
2023-05-19 Format file and resolve clippy warnings
    [main.rs]
2023-05-19 Revert "Shortcuts to activate/deactivate timer"
    This reverts commit 8bfbbdd92279ec5402a5a34bf16261f0ad9dbc81.
    [tool.py]
2023-05-19 Set a maximum of 150 for the input inbox. Above this value it has been observed a crash of the STM32
    [tool.py]
2023-11-16 Updated PCB and gerber files
    [analog.kicad_sch, cbank.kicad_sch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]
2023-12-07 Removed manual PWM settings
    Manual settings for PWM are not useful anymore thanks to the PID mode.
2023-12-07 Always enable PID
2024-02-09 Track possible errors of the set_pwm_parameters done by ADC
    [main.rs, silicontoaster.py]
2024-02-09 Rewording, and prevent data to be sent back
    [tool.py]
2024-05-24 Renamed hw folder to hardware
    [analog.kicad_sch, cbank.kicad_sch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]
2025-10-09 Spring cleaning for bringup tooling (#3)
    * Ignore raw flash images
    * Add building and flashing debug variant to makefile
    * Use Python interpreter from env/search path
    This allows to use a custom version and virtual environments
    * Disable ADC control/voltage controller for calibration
    The ADC contron/voltage controller overwrites PWM settings. It got
    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
